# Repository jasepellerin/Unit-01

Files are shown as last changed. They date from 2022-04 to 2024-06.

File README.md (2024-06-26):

# Unit-01 Firmware & Keymap

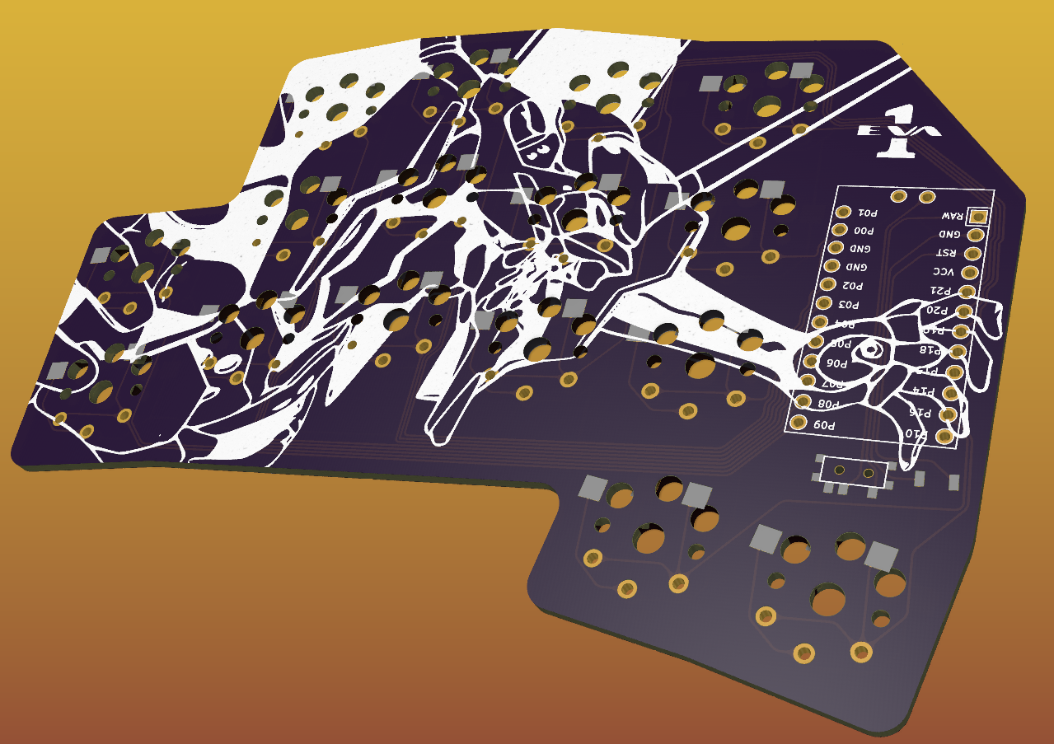
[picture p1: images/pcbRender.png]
Unit-01 PCB


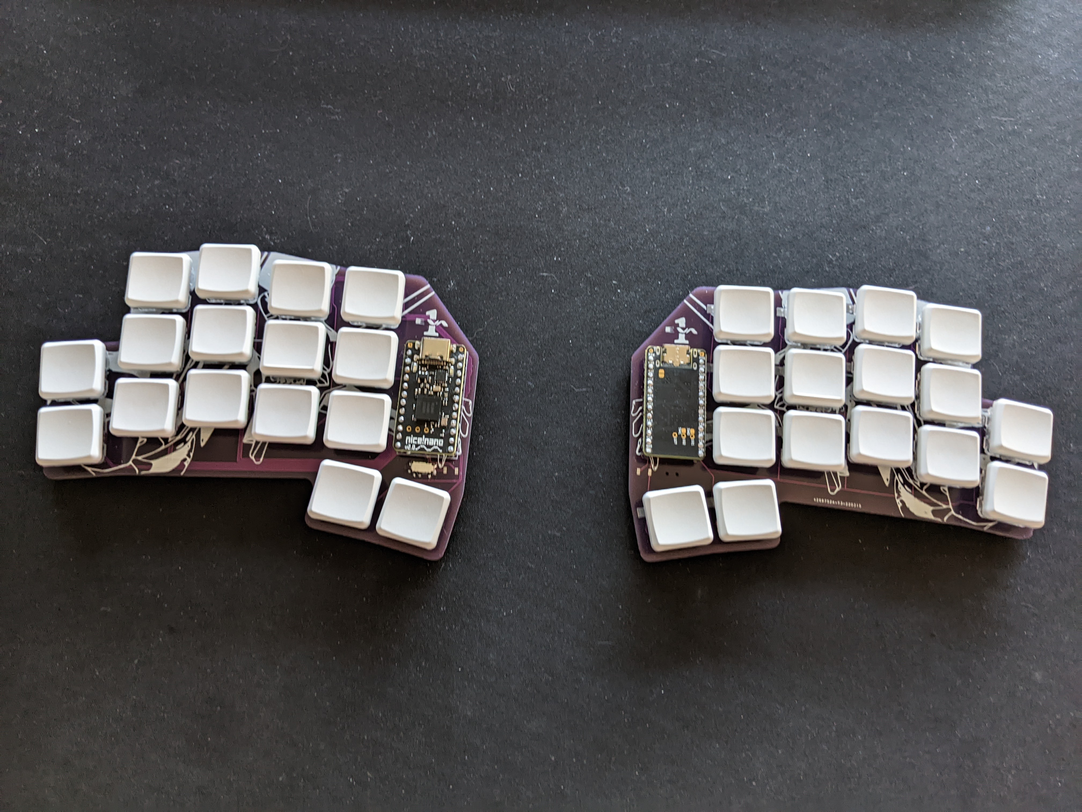
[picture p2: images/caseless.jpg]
Unit-01 Caseless


Unit-01 Complete

## What is this?

Unit-01 is the first keyboard I've designed and my first real foray into electronics as a whole. Unit-01 is a split, ergonomic, columnar, bluetooth, 32-key keyboard designed to be built using [nice!nano](https://nicekeyboards.com/nice-nano/) boards and Kailh Choc switches.

## Repo info

- Top level - ZMK config and related files
- "ergogen" - files related to the tool used to design the PCB and basic case elements
- "case" - case models and related files

## ZMK Process

### Shield creation / basic setup

Started by creating `boards/shields` files manually based on the [card](https://github.com/benvallack/zmk-config-card/tree/master/config/boards/shields/card) and the [a_dux](https://github.com/zmkfirmware/zmk/tree/main/app/boards/shields/a_dux)

### Initial key mapping

Moved into using [keymapper](https://www.keymapper.dev/layout) to generate base key layout with layers

- Start with 12 columns and 4 rows
- Delete the keys we don't need (double click)
- Scooch the right side over a bit (15 or so)
- Backup often :D

### Complex key mapping

Moved back into the raw keymap file for more precise control over the keys

## How to run the formatter

1. Commit or save your current work in case things get wild
1. Add line breaks between your rows to define the basic shape of your board
1. Steal the `format.ts` file and put it wherever you like
1. Install a typescript runner like [esrun](https://www.npmjs.com/package/@digitak/esrun) with `npm i -g @digitak/esrun`
1. Add your `filePath` and `desiredKeyCharacters` variables in `format.ts`
1. Run with esrun format.ts
1. Tweak the output to match your formatting needs
1. Run again after you change stuff :D

---

## Project log

### Initial Idea

I had been curious about split ergonomic keyboards for a few years when I saw a few of Ben Vallack's videos on small custom keyboards. [This one in particular](https://www.youtube.com/watch?v=UKfeJrRIcxw) sparked my interest in designing and building my own board. I asked loads of questions on various Discord servers along the way, and sincerely appreciate all the help I received from the community.

### Ideation

I did some research to learn about different switch options and elements I might want on my board. I started looking other people's builds, like the [Architeuthis dux](https://github.com/tapioki/cephalopoda/tree/main/Architeuthis%20dux) and the [card](https://github.com/benvallack/ergogen/blob/master/config.yaml). This helped me decide on the basic shape of the board and how many keys it would have.

### PCB Design (Ergogen)

I began by measuring the natural paths of my fingers on a site called [Ergopad](https://pashutk.ru/ergopad/). Then I plugged that info into [the unofficial Ergogen frontend](https://ergogen.cache.works/) and spent probably 25 hours learning the syntax and tweaking positions.

Then I started tweaking the exported file in Kicad. While adding my traces, I kept learning new things which led me back into Ergogen for another iteration cycle. Overall, this process probably took 15 more hours.

### Part Ordering

At this time, I had all the necessary files to start ordering parts. Here's the total cost of parts I ordered (a detailed breakdown is available by expanding the section below):

**Total part costs**

| Item | Price |
| :--- | ---: |
| Subtotal | $134.81 |
| S/H |  $19.48 |
| Grand Total | $154.29 |

<details>
  <summary>Detailed cost breakdown</summary>

[Boardsource](https://boardsource.xyz/)

| Item | Price |
| :--- | ----: |
| 40x Kailh Choc hotswap sockets | $6 |
| S/H | $4 |
| Order total | $10 |

[MKULTRA](https://mkultra.click/)

| Item |  Price |
| :--- | -----: |
| 40x Kailh Choc Switches (Silver) | $28.60 |
| White MBK Choc Keycaps (Alphas)  | $15 |
| S/H |  $5.59 |
| Order total | $49.19 |

[Little Keyboards](https://www.littlekeyboards.com/)

| Item |  Price |
| :--- | -----: |
| 2x nice!nano v2.0 | $49.98 |
| 2x Battery Combo for nice!nano Controller | $23.98 |
| S/H |  $4.83 |
| Total | $78.79 |

[JLCPCB](https://jlcpcb.com/)

| Item |  Price |
| :--- | -----: |
| 5x Custom PCB |  $9.25 |
| S/H |  $4.06 |
| Total | $13.31 |

[LCSC](https://lcsc.com/) - Part of a larger order

| Item | Price |
| :--- | ----: |
| Buttons | ~$2 |
| S/H | ~1 |
| Total | $3 |

</details>

### Assembly

After I received all the parts, I spent ~4 hours soldering everything. This step took a while since this was the first time I've ever soldered anything. Overall, it was pretty straightforward and I could feel myself getting more comfortable as I went.

I then spent around 8 hours debugging and fixing mistakes before I finally had a working keyboard.

### Firmware (ZMK)

The next step was setting up the firmware using [ZMK](https://zmk.dev/docs/), which probably took around 4 hours to learn and customize. I expect spend even more time on this stage getting all the keys laid out just how I want them.

### Case Design (Fusion 360)

Once everything was working to my liking, I decided to design a case for the keyboard. I spent probably 5 hours designing the case and another 1-2 hours messing with the 3D printer and fitting everything together.

### Conclusion

Overall, this build took me around 60 hours to complete. I started out not knowing anything about keyboard building or PCB design, I didn't even know how to solder!

I'm extremely pleased with how the board has turned out and am excited to actually use it now that it's done :D

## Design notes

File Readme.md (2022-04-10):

# Unit01 Firmware & Keymap

Unit 01 PCB

## TODO

- Formatter should fail if it can't fit everything (show which line is too long)
- Formatter should maintain the spacing between halves if possible
- Make releases show the generated firmware

## Repo info

- Top level - ZMK config and related files
- "ergogen" - files related to the tool used to design the PCB and basic case elements
- "case" - case models and related files

## How to run the formatter

1. Commit or save your current work in case things get wild
1. Add line breaks between your rows to define the basic shape of your board
1. Steal the `format.ts` file and put it wherever you like
1. Install a typescript runner like [esrun](https://www.npmjs.com/package/@digitak/esrun) with `npm i -g @digitak/esrun`
1. Add your `filePath` and `desiredKeyCharacters` variables in `format.ts`
1. Run with esrun format.ts
1. Tweak the output to match your formatting needs
1. Run again after you change stuff :D

## ZMK Process

### Shield creation / basic setup

Started by creating `boards/shields` files manually based on the [card](https://github.com/benvallack/zmk-config-card/tree/master/config/boards/shields/card) and the [a_dux](https://github.com/zmkfirmware/zmk/tree/main/app/boards/shields/a_dux)

### Initial key mapping

Moved into using [keymapper](https://www.keymapper.dev/layout) to generate base key layout with layers

- Start with 12 columns and 4 rows
- Delete the keys we don't need (double click)
- Scooch the right side over a bit (15 or so)
- Backup often :D

### Complex key mapping

Moved back into the raw keymap file for more precise control over the keys

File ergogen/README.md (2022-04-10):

# Ergogen

Ergogen is a keyboard generator that aims to provide a common configuration format to describe **ergonomic** 2D layouts, and generate automatic plates, cases, and (un-routed) PCBs for them.
The project grew out of (and is an integral part of) the [Absolem keyboard](https://zealot.hu/absolem), and shares its [Discord server](https://discord.gg/nbKcAZB) as well.

For usage and config information, please refer to the [docs](https://docs.ergogen.xyz).

## How to use

The main file to mess with is "config.yaml", which describes how the keyboard should be constructed using Ergogen's syntax. Pasting that file's contents into [this site](https://ergogen.cache.works/) will build the 2D and 3D representations of the keyboard and basic case structure.

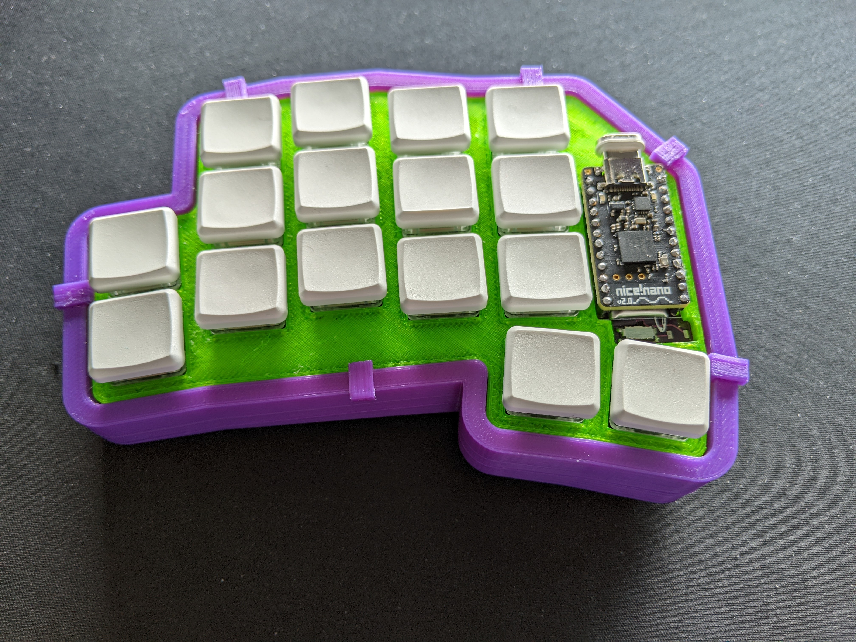
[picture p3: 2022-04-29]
images/case.jpg

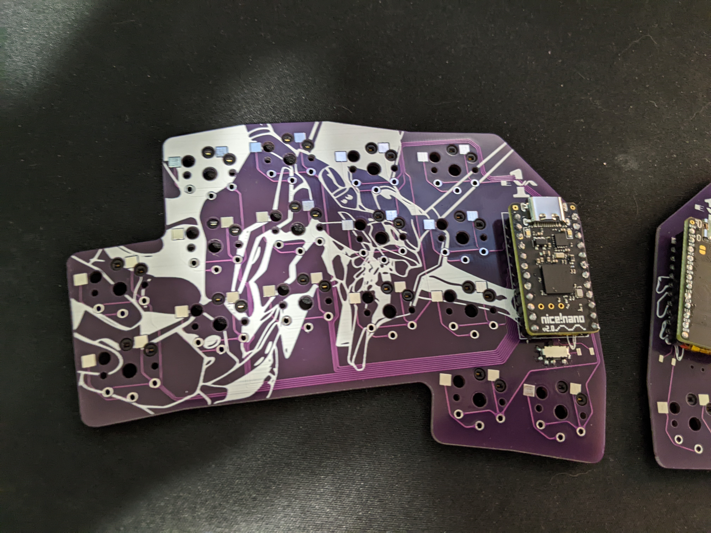
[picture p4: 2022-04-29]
images/pcbWithNano.jpg

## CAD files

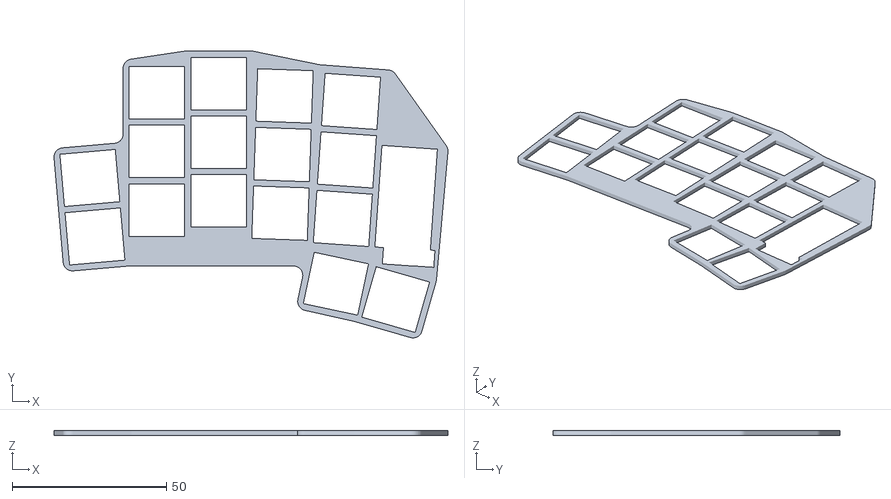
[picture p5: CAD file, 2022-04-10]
case/plate1.stl
127.6 x 92.9 x 1.50

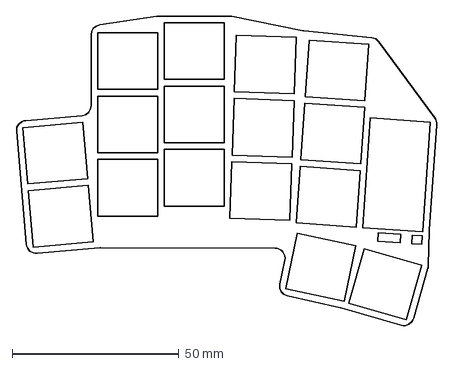
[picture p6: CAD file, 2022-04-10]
ergogen/kicad/outlines/panelWithKeys.dxf
126.3 x 93.2 mm

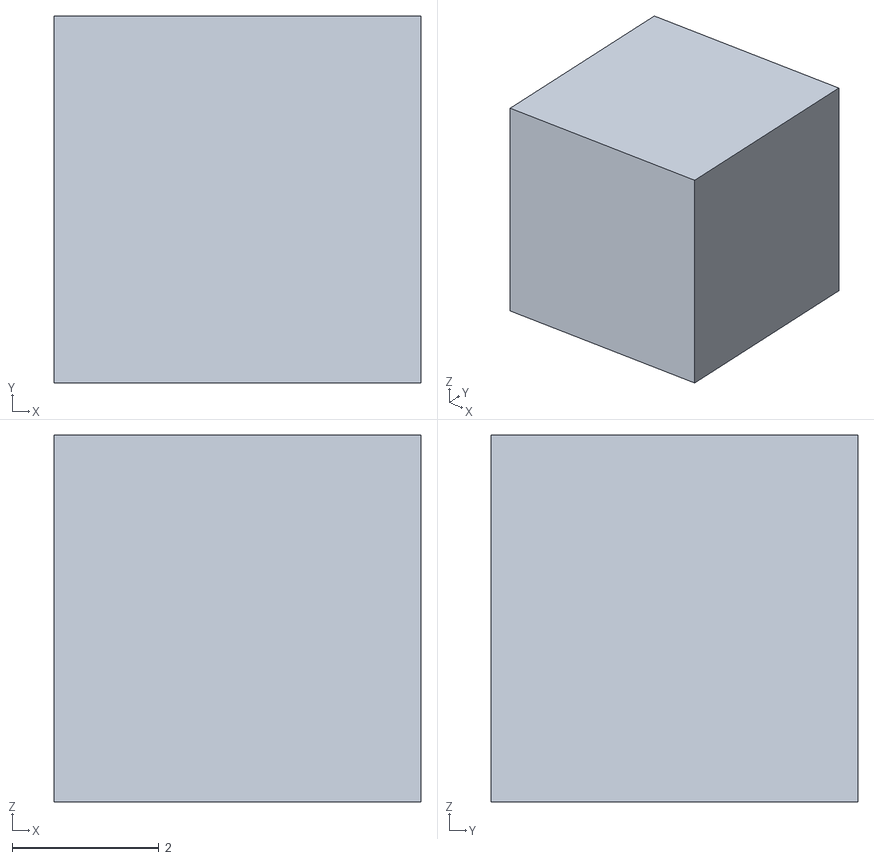
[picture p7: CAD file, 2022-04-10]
ergogen/test/cases/001_cube___cases_cube_stl.stl
5.00 x 5.00 x 5.00

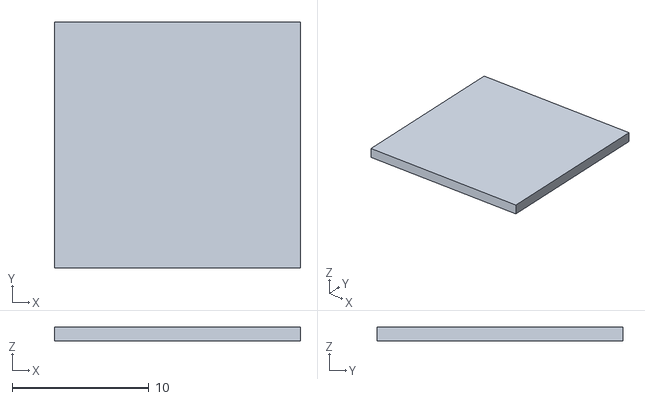
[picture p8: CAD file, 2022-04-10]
ergogen/test/cli/big/reference/cases/_export.stl
18.0 x 18.0 x 1.00

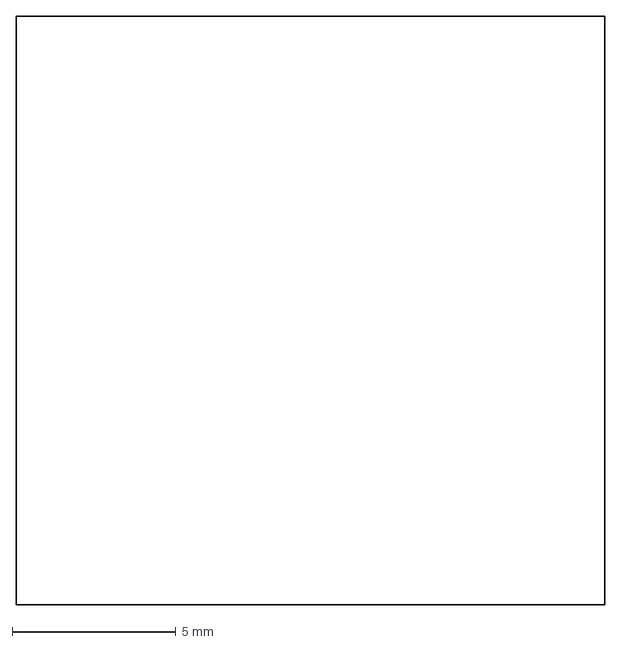
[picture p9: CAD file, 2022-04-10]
ergogen/test/cli/big/reference/outlines/_export.dxf
18.0 x 18.0 mm

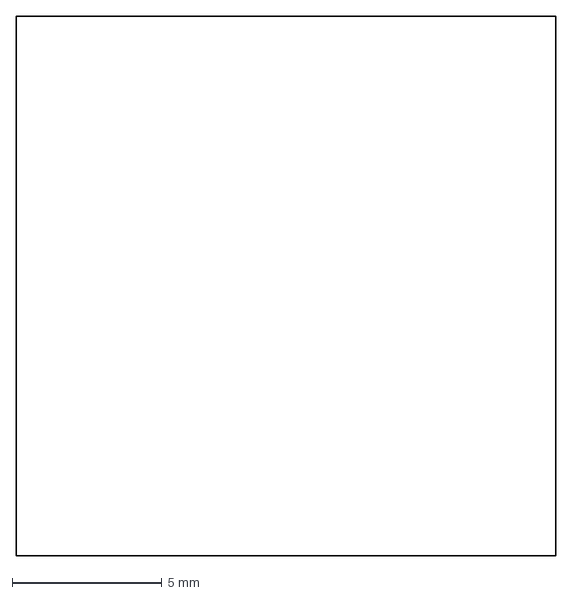
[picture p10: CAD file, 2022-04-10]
ergogen/test/cli/big/reference/points/demo.dxf
18.0 x 18.0 mm

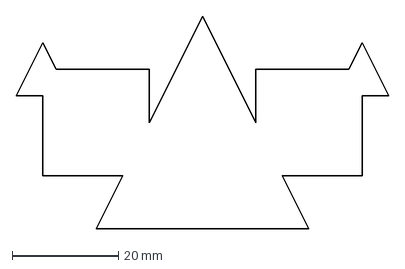
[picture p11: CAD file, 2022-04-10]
ergogen/test/outlines/polygons___outlines_outline_dxf.dxf
70.0 x 40.0 mm

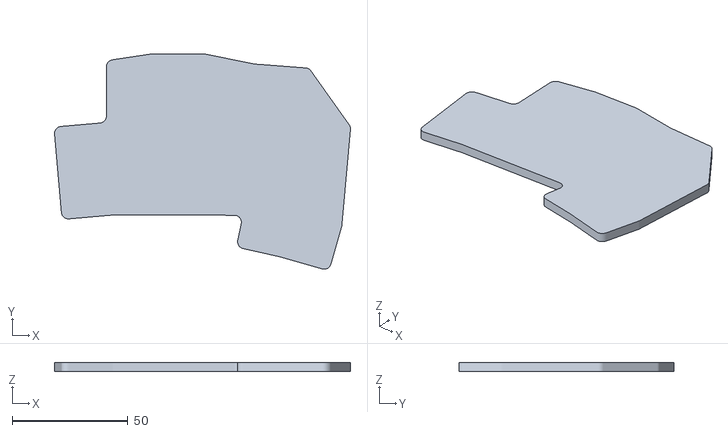
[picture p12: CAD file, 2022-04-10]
case/case1.stl
127.6 x 92.9 x 4.00

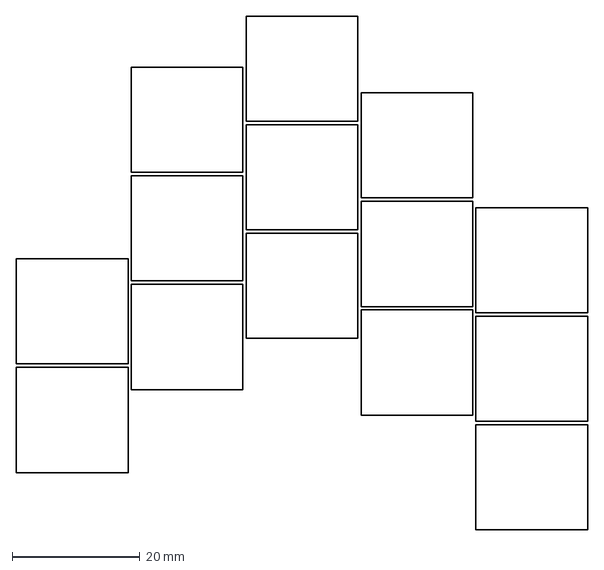
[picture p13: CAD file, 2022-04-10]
ergogen/kicad/outlines/keycap_outlines.dxf
89.5 x 80.5 mm

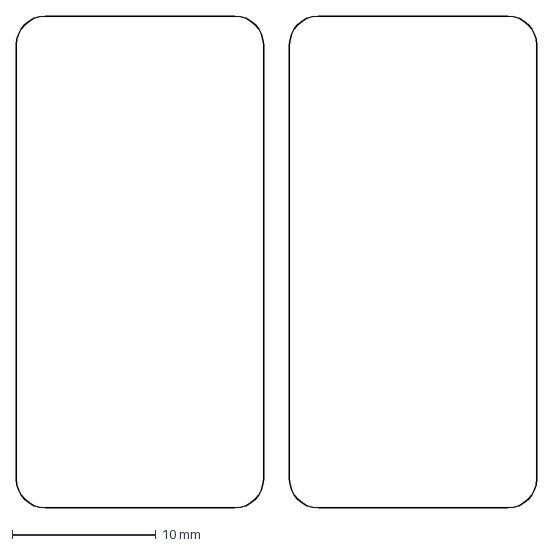
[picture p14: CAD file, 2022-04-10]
ergogen/test/outlines/fillet___outlines_fillet_dxf.dxf
36.2 x 34.2 mm

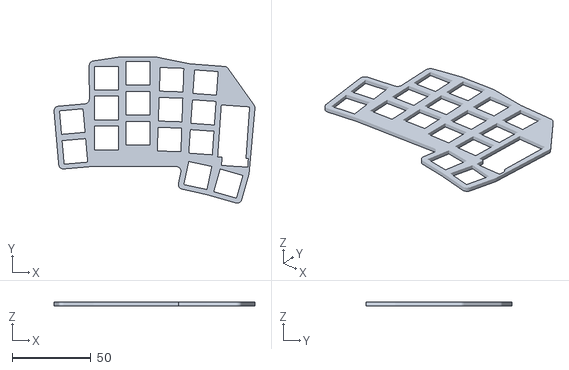
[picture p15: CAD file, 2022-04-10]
case/plate2.stl
127.6 x 92.9 x 2.25

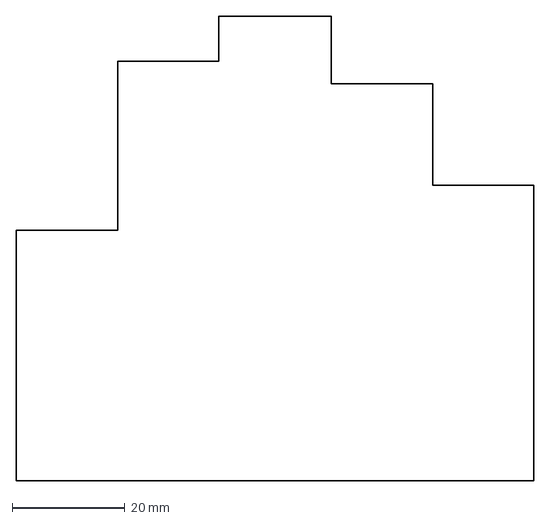
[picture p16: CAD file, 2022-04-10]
ergogen/kicad/outlines/raw.dxf
92.0 x 82.5 mm

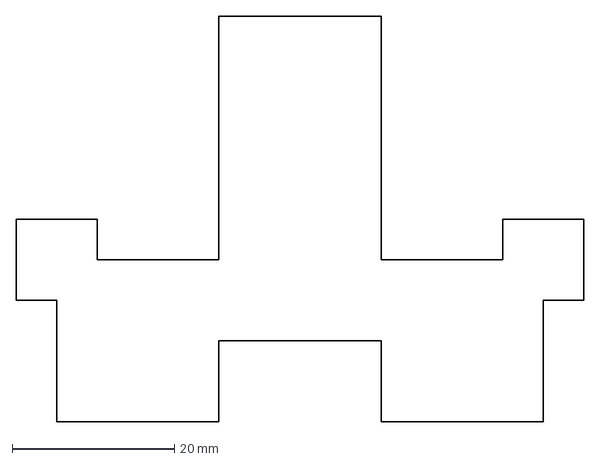
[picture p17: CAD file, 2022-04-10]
ergogen/test/outlines/rectangles___outlines_outline_dxf.dxf
70.0 x 50.0 mm

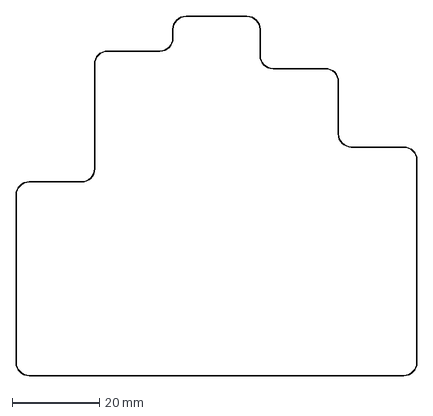
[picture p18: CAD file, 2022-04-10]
ergogen/kicad/outlines/cutout.dxf
92.0 x 82.5 mm

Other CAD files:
ergogen/test/outlines/circles___outlines_outline_dxf.dxf
case/Case.f3d
case/Unit-01 Case v10.f3d
ergogen/test/outlines/affect_mirror___outlines_test_dxf.dxf
ergogen/test/outlines/basic___outlines_outline_dxf.dxf
ergogen/test/outlines/gluing___outlines_optout_dxf.dxf
ergogen/test/outlines/gluing___outlines_outline_dxf.dxf

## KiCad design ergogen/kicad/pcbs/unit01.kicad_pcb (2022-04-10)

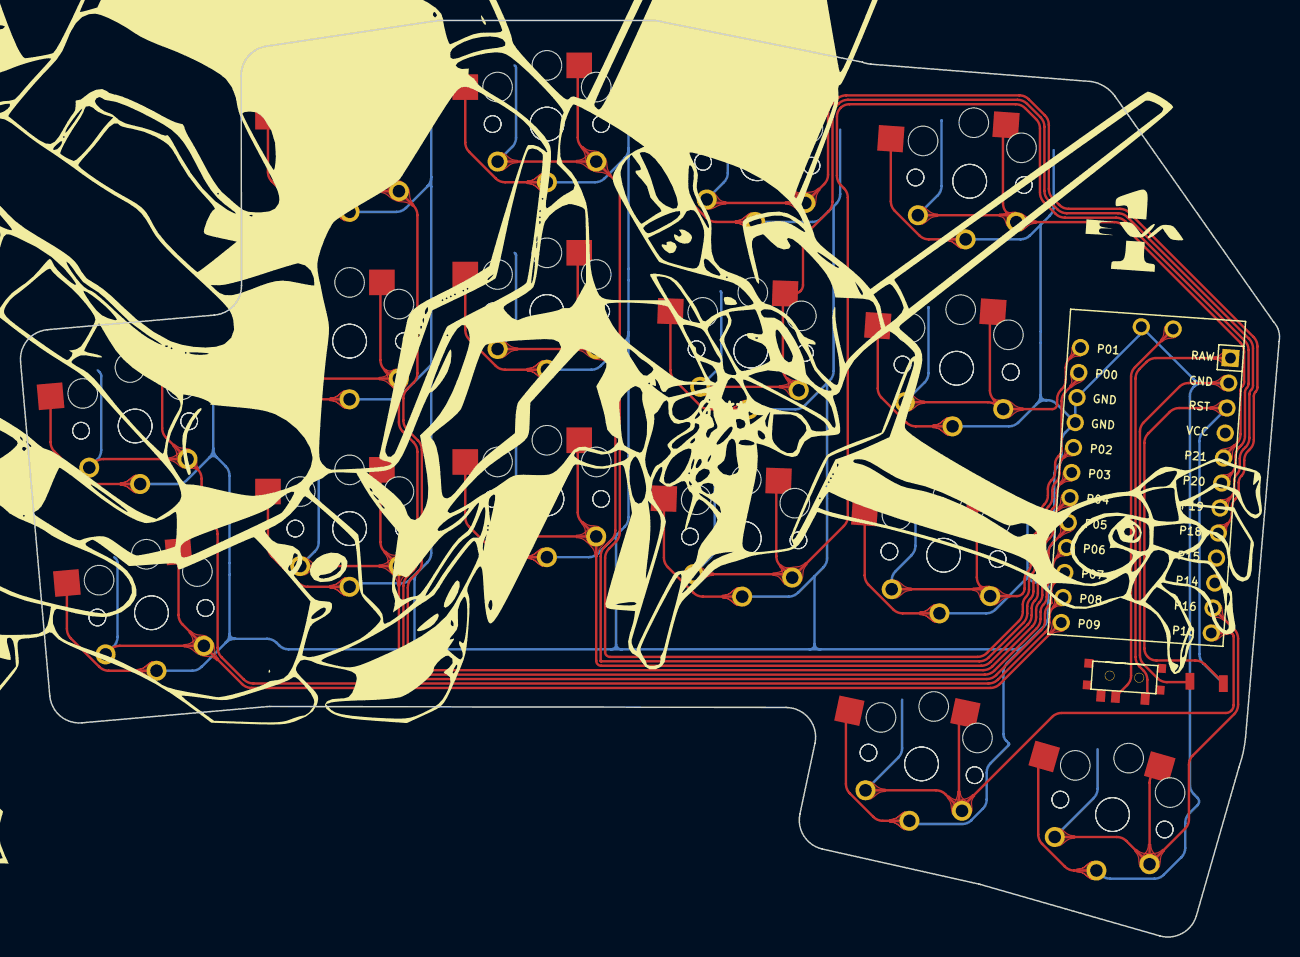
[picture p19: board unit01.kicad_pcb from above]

Board: 2 copper layers, 127.6 x 92.9 mm, 34 parts (0 on the bottom side), 18 nets.

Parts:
MCU1: ProMicro
S1, S2, S3, S4, S5, S6, S7, S8, S9, S10, S11, S12, S13, S14, S15, S16, S17, S18, S19, S20, S21, S22, S23, S24, S25, S26, S27, S28, S29, S30, S31, S32: PG1350
T1: SPDT_C128955

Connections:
GND: MCU1.2, MCU1.15, MCU1.16, S1.2, S2.2, S3.2, S4.2, S5.2, S6.2, S7.2, S8.2, S9.2, S10.2, S11.2, S12.2, S13.2, S14.2, S15.2, S16.2, S17.2, S18.2, S19.2, S20.2, S21.2, S22.2, S23.2, S24.2, S25.2, S26.2, S27.2, S28.2, S29.2, S30.2, S31.2, S32.2
P0: MCU1.14, S23.1, S24.1
P1: MCU1.13, S25.1, S26.1
P2: MCU1.17, S15.1, S16.1
P3: MCU1.18, S13.1, S14.1
P4: MCU1.19, S11.1, S12.1
P5: MCU1.20, S9.1, S10.1
P6: MCU1.21, S7.1, S8.1
P7: MCU1.22, S5.1, S6.1
P8: MCU1.23, S3.1, S4.1
P9: MCU1.24, S1.1, S2.1
P10: MCU1.12, S29.1, S30.1
P16: MCU1.11, S31.1, S32.1
P18: MCU1.8, S21.1, S22.1
P19: MCU1.7, S19.1, S20.1
P20: MCU1.6, S17.1, S18.1
P21: MCU1.5, S27.1, S28.1
RAW: MCU1.1, T1.1

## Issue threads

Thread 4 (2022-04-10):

PCB - Flip power switch footprint

jasepellerin, 2022-04-10:

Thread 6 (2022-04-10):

PCB - Use reversible controller footprint

jasepellerin, 2022-04-10:
- Add controller silk to bottom as well
- If applicable, also flip the text on the footprint silk

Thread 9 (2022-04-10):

PCB - Flip switch footprints

jasepellerin, 2022-04-10:
Not sure if this is worth doing, but the switches do look upside-down on the board

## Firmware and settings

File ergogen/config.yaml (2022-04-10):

units:
  halfKeyW: 0.5 cx
  halfKeyH: 0.5 cy
  paddingX: 2
  paddingY: 2
  pinkyRotate: 5
  ringRotate: -5
  indexRotate: -2
  innerRotate: -2
  thumbRotate: -8
  thumbFarRotate: -4

  buttonWidth: 3
  buttonHeight: 2.5

  mcuHeight: 18
  mcuWidth: 33

  switchWidth: 6.7
  switchHeight: 2.6

  # Used for demo.dxf
  visual_x: 1
  visual_y: 1

points.zones:
  matrix:
    key: &key_attributes
      width: &key_width 18
      height: &key_height 17
      tags:
        key_switch: true
      footprints:
        choc_hotswap:
          type: choc
          nets:
            from: =key_net
            to: GND
          params:
            keycaps: true
            reverse: true
            hotswap: true
        choc:
          type: choc
          anchor:
            rotate: 180
          nets:
            from: =key_net
            to: GND
          params:
            reverse: true
            keycaps: true
    rows:
      bottom:
      home:
      top:
    columns:
      pinky:
        rotate: pinkyRotate
        rows:
          top.skip: true
          home.key_net: P8
          bottom.key_net: P9
      ring:
        rotate: ringRotate
        stagger: 6.75
        spread: 20.75
        rows:
          top.key_net: P5
          home.key_net: P6
          bottom.key_net: P7
      middle:
        stagger: 3
        spread: 20
        rows:
          top.key_net: P2
          home.key_net: P3
          bottom.key_net: P4
      index:
        rotate: indexRotate
        stagger: -4
        spread: 20
        rows:
          top.key_net: P18
          home.key_net: P19
          bottom.key_net: P20
      inner:
        spread: 20.25
        stagger: -1
        rotate: innerRotate
        rows:
          top.key_net: P21
          home.key_net: P1
          bottom.key_net: P0
  thumbfan:
    key: *key_attributes
    anchor:
      ref: matrix_inner_bottom
      shift: [-7, -19]
    columns:
      home:
        rotate: thumbRotate
        spread: 6.25
        stagger: -2.25
        key.key_net: P10
      far:
        rotate: thumbFarRotate
        stagger: -1
        spread: 20
        key.key_net: P16
    rows:
      thumb:

  mcu:
    key:
      name: mcu
      height: mcuHeight
      width: mcuWidth
      key_net:
      rotate: 270
      tags:
        mcu: true
    anchor:
      - ref: matrix_inner_home
        shift: [cx + paddingX, -halfKeyH - 1.25paddingY]

  button:
    key:
      name: button
      height: buttonHeight
      width: buttonWidth
      key_net:
      rotate: 90
      tags:
        button: true
    anchor:
      - ref: mcu
        shift: [cy + paddingY, halfKeyW - .75paddingX]

  switch:
    key:
      name: switch
      height: switchHeight
      width: switchWidth
      key_net:
      tags:
        switch: true
    anchor:
      - ref: button
        shift: [-buttonWidth - paddingX - .5 switchWidth, 0]

outlines.exports:
  _outer:
    - type: polygon
      points:
        - ref: matrix_inner_home
          shift: [halfKeyW + 2.75paddingX + mcuHeight, 3paddingY]
        - ref: thumbfan_far_thumb
          shift: [halfKeyW + 1paddingX, halfKeyH + .5paddingY]
        - ref: thumbfan_far_thumb
          shift: [halfKeyW + paddingX, -halfKeyH - paddingY]
        - ref: thumbfan_far_thumb
          shift: [-halfKeyW - paddingX, -halfKeyH - paddingY]
        - ref: thumbfan_home_thumb
          shift: [-halfKeyW - paddingX, -halfKeyH - paddingY]
        - ref: thumbfan_home_thumb
          shift: [-halfKeyW - paddingX, halfKeyH + paddingY -  7]
        - ref: matrix_pinky_bottom
          shift: [halfKeyW + paddingX, -halfKeyH - paddingY]
        - ref: matrix_pinky_bottom
          shift: [-halfKeyW - paddingX, -halfKeyH - paddingY]
        - ref: matrix_pinky_home
          shift: [-halfKeyW - paddingX, halfKeyH + paddingY]
        - ref: matrix_pinky_home
          shift: [halfKeyW + paddingX + .75, halfKeyH + paddingY]
        - ref: matrix_ring_top
          shift: [-halfKeyW - paddingX, halfKeyH + paddingY]
        - ref: matrix_middle_top
          shift: [-halfKeyW - paddingX, halfKeyH + paddingY]
        - ref: matrix_middle_top
          shift: [halfKeyW + paddingX, halfKeyH + paddingY]
        - ref: matrix_index_top
          shift: [halfKeyW + paddingX, halfKeyH + paddingY]
        - ref: matrix_inner_top
          shift: [halfKeyW + 1.9paddingX, halfKeyH + 1.25paddingY]
  _panel:
    - name: _outer
      fillet: 3
  panel:
    - _panel
  _case:
    - _panel
  case-inner:
    - _panel
    - operation: subtract
      name: _panel
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

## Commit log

2022-03-12 Remove lots of cruft, tighten up the outline
2022-03-12 Small thumbpad tweak, start wiring
2022-03-12 More wiring, tweak bottom of outline
2022-03-12 Add wiring space at the bottom, re-add choc hotswap (whoops!)
2022-03-13 Bring in thumb fan
2022-03-13 Remove unused stuff
    [demo.dxf]
2022-03-13 Add footprints
2022-03-13 Export new footprints
2022-03-13 Remove battery footprint
2022-03-14 Add power switch and reset button
2022-03-14 Re-add button and switch
2022-03-14 Fix button nets
2022-03-14 Tweak button, add button connector, then comment out switch and connector for the first round
2022-03-14 Re-add switch, add batteryPads, move switch over a bit
2022-03-14 Add battery pads, remove switch
2022-03-14 Swapping some pins while wiring things up in kicad
    [config.yaml]
2022-03-14 Add kicad files
    [cutout.dxf, keycap_outlines.dxf, main.kicad_pcb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]
2022-03-15 Generate pcb
    [polished-B_Cu.gbr, polished-B_Mask.gbr, polished-B_Paste.gbr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]
2022-03-17 Make outline match tweaks I made in Kicad
2022-03-17 Add basic case
2022-03-17 Add adjusted kicad, based on tweaks to ergogen
    [adjusted.kicad_pcb]
2022-04-04 Add bootloader button, fix number of columns
2022-04-04 Trying with built boards
2022-04-04 Trying with built boards - fixed
2022-04-04 Trying with built boards - again
2022-04-05 Case stuff
2022-04-07 Remove logging, increase BT power
2022-04-10 Add ergogen repo into its own directory
    [001_cube___cases_cube_stl.stl, _export.dxf, _export.kicad_pcb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]
2022-04-10 Add case files and render image
    [Case.f3d, case1.stl, case2.stl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]
2022-04-10 Remove old kicad files, rename
    [adjusted.kicad_pcb, main.kicad_pcb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]
2022-04-10 Remove old kicad files, rename, move image to top level folder
    [unit01-B_Cu.gbr, unit01-B_Mask.gbr, unit01-B_Paste.gbr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]
2022-04-11 Added more depth to main case body
    [Unit-01 Case v10.f3d]
2022-04-13 Updated case
    [Case.f3d]
2022-04-26 Trying a couple things
